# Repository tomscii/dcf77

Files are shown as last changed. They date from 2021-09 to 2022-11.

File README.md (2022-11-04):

## DCF77 clock and temperature/humidity sensor with ATmega328P

(https://tomscii.sig7.se/images/dcf77/final.jpg)

Read the story: https://tomscii.sig7.se/dcf77

### Project organisation

- `doc` - documentation, design notes
- `doc/contrib` - datasheets and specs
- `src` - software (MCU)
- `sim` - simulator (simavr)
- `hw` - hardware design (KiCAD)

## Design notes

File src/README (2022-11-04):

Type 'make' in this directory to compile the firmware.

Type 'make dude' to program the firmware into the device connected to
the AVR programmer.

Keep in mind: the CPU core runs at a clock speed of 250 kHz (much
lower than usual) to save power. This has a number of implications,
e.g., the USART runs at a baudrate of 2400.

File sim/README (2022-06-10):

To get up and running, install simavr (command for debian bullseye):

    sudo apt-get install simavr libsimavr2 libsimavrparts1 libsimavr-dev libelf-dev

The simgui (running in a subprocess, spawned by simulator) requires tcl/tk, while
the serial console uses picocom.

    sudo apt-get install picocom tk

Type `make' in this directory to build the firmware (with simulation
bits) and the simulator itself.

Run the simulation:
    export SIMAVR_UART_XTERM=1
    ./simulator

Open the trace:
    gtkwave trace.vcd

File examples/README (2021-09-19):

Small code examples of programming the AVR with avr-libc,
written with the aim of research and development of certain features.
Contains samples copied from Internet sources.

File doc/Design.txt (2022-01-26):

# DCF77 clock
Planned features:
- DCF77-driven
	- HH:MM:SS, YY.mm.dd, day-of-week
- programmable alarm sound
- stopwatch
- adjustable backlight
- temperature+humidity sensor
- random number generator (6 digits simulating one dice each, with numbers 1-6)
- serial console output (and maybe input) via FTDI header
- powered by 2x AA batteries

DCF77 receiver module
https://www.conrad.com/p/dcf-receiver-module-641138-suitable-for-series-c-control-641138
(we already have one, and it works!)

ATMEGA328P developer board, Arduino Nano-compatible, with soldered pins
https://www.electrokit.com/produkt/utvecklingskort-atmega328p-nano-kompatibelt-monterat/ 79.00 kr

(ATMEGA328P developer board, Arduino Nano-compatible, WITHOUT soldered pins
https://www.electrokit.com/produkt/utvecklingskort-atmega328p-nano-kompatibelt/ 79.00 kr)

(LCD 0.5" 6-digit 7-segment reflective
https://www.electrokit.com/produkt/lcd-0-5-6-siffror-reflective/ 67.50 kr)

(LCD 0.5" 6-digit 7-segment transflective
https://www.electrokit.com/produkt/lcd-0-5-6-siffror-transflective/ 73.75 kr)

LCD 0.5" 6-digit 7-segment transmissive
https://www.electrokit.com/produkt/lcd-0-5-6-siffror-transmissive/ 39.00 kr

Backlight for LCD
https://www.electrokit.com/produkt/bakgrundsbelysning-for-lcd-78-5-x-23mm/ 30.00 kr

Note: it is the transmissive LCD that works best with the backlight.
Having the backlight module behind the LCD, even with no light, makes
the LCD clearly visible (gives it a clear background).

74HC595 DIP-16 8-bit shift register with output latches
https://www.electrokit.com/produkt/74hc595-dip-16-8-bit-shift-register-with-output-latches/
53.10 kr (10 pcs.)
https://www.electrokit.com/produkt/dil-hallare-16-pin/ 2.00 kr (x6)

ATmega328p
https://www.electrokit.com/produkt/atmega328p-pu-dip-28n-8-bit-mcu-flash-32k-picopower/
39.00 kr (x3)
https://www.electrokit.com/produkt/dil-hallare-28-pin-0-3/ 3.50 kr

Piezo (buzzer)
https://www.electrokit.com/produkt/piezoelement-o12x5-5mm/ 15.00 kr

Tryckknapp PCB
https://www.electrokit.com/produkt/tryckknapp-pcb-12x12x8mm/ 9.00 kr (x4)

Temp+humidity sensor
https://www.electrokit.com/produkt/temp-fuktsensor-rht03/ 99.00 kr
connector on mainboard to hold it near the backside
https://www.electrokit.com/produkt/hylslist-2-54mm-1x4p-vinklad/ 9.00 kr

Battery holder
https://www.electrokit.com/produkt/batterihallare-2xaa-sladd/ 9.00 kr
https://www.electrokit.com/produkt/jst-rcy-sats-med-hane-hona/ 8.00 kr
Megj.: PCB-be forrasztott derekszogu 2 polusu tuskesorra megy az aljzat, elemtartora a dugo.

Proto-board
https://www.electrokit.com/produkt/experimentkort-for-pc002/ 30.00 kr
(https://www.electrokit.com/produkt/experimentkort-for-41015692/ 29.0 kr)

Doboz
https://www.electrokit.com/produkt/apparatlada-pc002-med-haltagning-gra/ (85x50x21) 15.00 kr
(https://www.electrokit.com/produkt/apparatlada-gra-100x60x25mm/ (100x60x25) 25.00 kr)

## IO port usage

- port X:
	- bit 0-5: 6-bit parallel output into 6 shifted lines (6x8 bits) driving LCD segment pins
	  (Further 6 bits can be obtained from directly using the LCD DATA output of our MCU.)
  - bit 6: CLK (all 74HC595 chips' SH_CP and ST_CP pins in one)
	- bit 7: OE (Output Enable) of all 6 shift registers
	  Note: we might not need this (wire to enable instead); we can put the LCD COM pin in tri-state.
- port Y:
	- bit 0: output, drives LCD module COM (common) pin
  - bit 1: drive background lighting LEDs (TODO provision 3 pins for RGB)
  - bit 2: output, drives buzzer
  - bit 3: input/output, connected to DHT22 sensor's DATA signal
  - bit 4: input from DCF77 receiver module
  - bit 5-7: input from 3 pushbuttons
+ UART RX, TX

1 - PC6 - RESET/ (AVRPROG)
2 - PD0 - RXD - to FTDI pin 4 (orange-TXD)
3 - PD1 - TXD - to FTDI pin 5 (yellow-RXD)
4 - PD2 - DHT22 DATA I/O
5 - PD3 - OC2B - PWM - LED R
6 - PD4 - DHT22 POWER
7 - VCC (POWER)
8 - GND (POWER)
9 - XTAL1 (OSC)
10 - XTAL2 (OSC)
11 - PD5 - OC0B - PWM - LED G
12 - PD6 - OC0A - PWM - PiezoBuzzer
13 - PD7 - DCF77 POWER
14 - PB0 - ICP1 - DCF77 S-

15 - PB1 - BUTTON2
16 - PB2 - BUTTON1
17 - PB3 - OC2A - PWM - LED B + MOSI (AVRPROG)
18 - PB4 - BUTTON0 + MISO (AVRPROG)
19 - PB5 - SCK (AVRPROG)
20 - AVCC (POWER)
21 - AREF (POWER)
22 - GND (POWER)
23 - PC0 - LCD DATA0
24 - PC1 - LCD DATA1
25 - PC2 - LCD DATA2
26 - PC3 - LCD CLK
27 - PC4 - LCD COM
28 - PC5 - LCD OE/

LED resistors: R 150, G 680, B 470 ohm.

## Component placement
Fit the processor on the same board as the display driver shift registers.
We only need sockets for the LCD module (2x25-pin socket rails near the long edges of the board) so we can remove the LCD and access the microchips underneath.

## Literature

ATmega328p datasheet: https://www.electrokit.com/uploads/productfile/40360/doc8161.pdf
Getting started guide: https://github.com/amirbawab/AVR-cheat-sheet

## Development

$ apt-get install gcc-avr binutils-avr avr-libc gdb-avr avrdude

$ avrdude -c usbtiny -p atmega328p
avrdude: AVR device initialized and ready to accept instructions
Reading | ################################################## | 100% 0.06s
avrdude: Device signature = 0x1e950f (probably m328p)
avrdude: safemode: Fuses OK (E:FF, H:D9, L:62)
avrdude done.  Thank you.

$ cat blink.c
#ifndef F_CPU
#define F_CPU 1000000UL
#endif

#include <avr/io.h>
#include <util/delay.h>

int main(void) {
        DDRC |= (1 << PC5);
        while (1) {

                // Toggle LED at port PC5
                PORTC ^= (1 << PC5);

                // Delay for 500ms
                _delay_ms(500);
        }
        return 0;
}

$ avr-gcc -Wall -g -Os -mmcu=atmega328p -o blink.bin blink.c
$ avr-objcopy -j .text -j .data -O ihex blink.bin blink.hex
$ avrdude -c usbtiny -p atmega328p -U flash:w:blink.hex

Device signature: 1E 95 0F = 0001 1110 1001 0101 0000 1111

To change the clock to using 40kHz crystal, program 0xE5 as the lower fuse bit value by adding -Ulfuse:w:0xe5:m to the avrdude command line. (Also change F_CPU above to 40000UL.)

Attention: from this point, use a low bitclock (-B 10kHz) or else the device won't answer!
Complete command line:
$ avrdude -c usbtiny -p atmega328p -B 10kHz -U flash:w:blink.hex -Ulfuse:w:0xe5:m

# Aux Supplies
Forraszfelszívó rézsodrony, hogy ki tudjam forrasztani a dcf77 modulra rakott csatit. A helyére tüskesor kerül, ami a főkártyán levő aljzatba csatlakozik.
https://www.electrokit.com/produkt/lodflata-2-7mm/ 35.00 kr
Fokartya aljzat (hatoldalon, hogy a dcf77 panel vele parhuzamos legyen):
https://www.electrokit.com/produkt/hylslist-2-54mm-1x8p-vinklad/ 15.00 kr

Forrasztoallomas
https://www.electrokit.com/produkt/lodstation-variabel-effekt-vtss4-ap-2/
199.00 kr

Sparkfun Pocket AVR programmer
https://www.electrokit.com/produkt/avr-pocket-programmer/
199 kr
Keszulekre programozo csatlakozo:
https://www.electrokit.com/produkt/idc-hane-pcb-6-pol-2-54mm/ 6.00 kr
https://www.electrokit.com/produkt/idc-hane-pcb-10-pol-2-54mm/ 5.04 kr
(https://www.electrokit.com/produkt/idc-hane-pcb-10-pol-vinklad-2-54mm/ 6.50 kr)
Megj.: valoszinuleg nem fer el egyik sem, sima 2x3-polusu tuskesor lesz beforrasztva.

- LEDs
  https://www.electrokit.com/produkt/led-3mm-rod-diffus-1300mcd/ 45.00 kr (10 pcs)
	https://www.electrokit.com/produkt/led-3mm-orange-diffus-600mcd/ 45.00 kr (10 pcs)
	https://www.electrokit.com/produkt/led-3mm-gron-diffus-70mcd/ 45.00 kr (10 pcs)
	https://www.electrokit.com/produkt/led-5mm-rod-diffus-1500mcd/ 5.00 kr
	https://www.electrokit.com/produkt/led-5mm-orange-diffus-700mcd/ 5.00 kr
	https://www.electrokit.com/produkt/led-5mm-gron-diffus-80mcd/ 5.00 kr
	https://www.electrokit.com/produkt/led-5mm-rgb-diffus-cc/ 6.00 kr

- Clock quartz, various freqs
  https://www.electrokit.com/produkt/kristall-16-0000-mhz-hc49-s/ 12.00 kr
  https://www.electrokit.com/produkt/kristall-8-000-mhz-hc-49-u-30-pf/ 12.00 kr
	https://www.electrokit.com/produkt/kristall-8-000mhz-o3x8mm-30ppm/ 5.00 kr
	https://www.electrokit.com/produkt/kristall-2mhz-hc-49-u/ 19.00 kr
	https://www.electrokit.com/produkt/kristall-100khz-o2x6mm-15pf-100ppm/ 25.00 kr
	https://www.electrokit.com/produkt/kristall-40-000khz-o3x8mm/ 15.00 kr
	https://www.electrokit.com/produkt/kristall-38-000khz-o3x8mm/ 12.00 kr

- Kondensatorsats keramisk 108st
  https://www.electrokit.com/produkt/kondensatorsats-keramisk-108-st/
	49.00 kr

- Stiftlist & hylslist
  https://www.electrokit.com/produkt-kategori/kontaktdon-2/stiftlist-hylslist/2-54mm/
	- kell 2 db 1x25 aljzat, az LCD modulnak
	  https://www.electrokit.com/produkt/hylslist-2-54mm-1x40p-svarvad-brytbar/ 15.00 kr x2

    https://www.electrokit.com/produkt/stiftlist-2-54mm-1x40p-brytbar/ 9.00 kr x4
    https://www.electrokit.com/produkt/stiftlist-2-54mm-1x40p-vinklad-brytbar/ 11.00 kr x2
		https://www.electrokit.com/produkt/stiftlist-2-54mm-2x40p-brytbar-guld/ 18.00 kr
		https://www.electrokit.com/produkt/stiftlist-2-54mm-2x40p-vinklad-brytbar/ 19.00 kr
		https://www.electrokit.com/produkt/hylslist-2-54mm-1x40p/ 19.00 kr x2
		https://www.electrokit.com/produkt/hylslist-2-54mm-2x20p/ 15.75 kr x2

- Breadboard
  https://www.electrokit.com/produkt/kopplingsdack-840-anslutningar/ 69.00 kr
	https://www.electrokit.com/produkt/kopplingstrad-byglar-for-kopplingsdack/ 59.00 kr
- https://www.electrokit.com/produkt/labbsladd-20-pin-15cm-hona-hane/ 29.00 kr
- https://www.electrokit.com/produkt/labbsladd-20-pin-15cm-hona-hona/ 29.00 kr

- Kabelskalare
  https://www.electrokit.com/produkt/kabelskalare-sjalvjusterande-velleman/ 69.00 kr

- Kopplingstråd
  https://www.electrokit.com/produkt/kopplingstrad-entradig-sats-60m/ 149.00 kr
	https://www.electrokit.com/produkt/kopplingstrad-flertradig-sats-60m/ 149.00 kr

- valami forrasztos proto-board (PCB helyett)
	https://www.electrokit.com/produkt/experimentkort-for-41015692/
	https://www.electrokit.com/produkt/experimentkort-1-hal-80x120mm-genomplaterade-hal/
	https://www.electrokit.com/produkt/experimentkort-1-hal-100x80-fr4/
	https://www.electrokit.com/produkt/experimentkort-1-hal-100x160-fr4/
	https://www.electrokit.com/produkt/experimentkort-breadboard-400-hal/

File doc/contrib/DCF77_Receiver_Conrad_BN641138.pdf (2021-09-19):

# Connection line DCF – Receiver

BN 641138

## Frankfurt

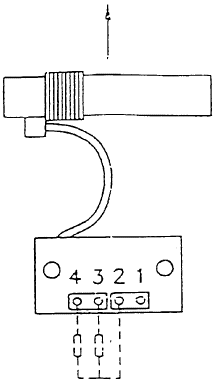
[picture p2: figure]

pull up resistance
if necessary

R > UB : 1 mA

1: Earth
2: + operating voltage 1.2 … 1.5 V-3: DCF output
4: DCF output inverted

Outputs 3 and 4 of open collectors npn max. 30 V 1 mA

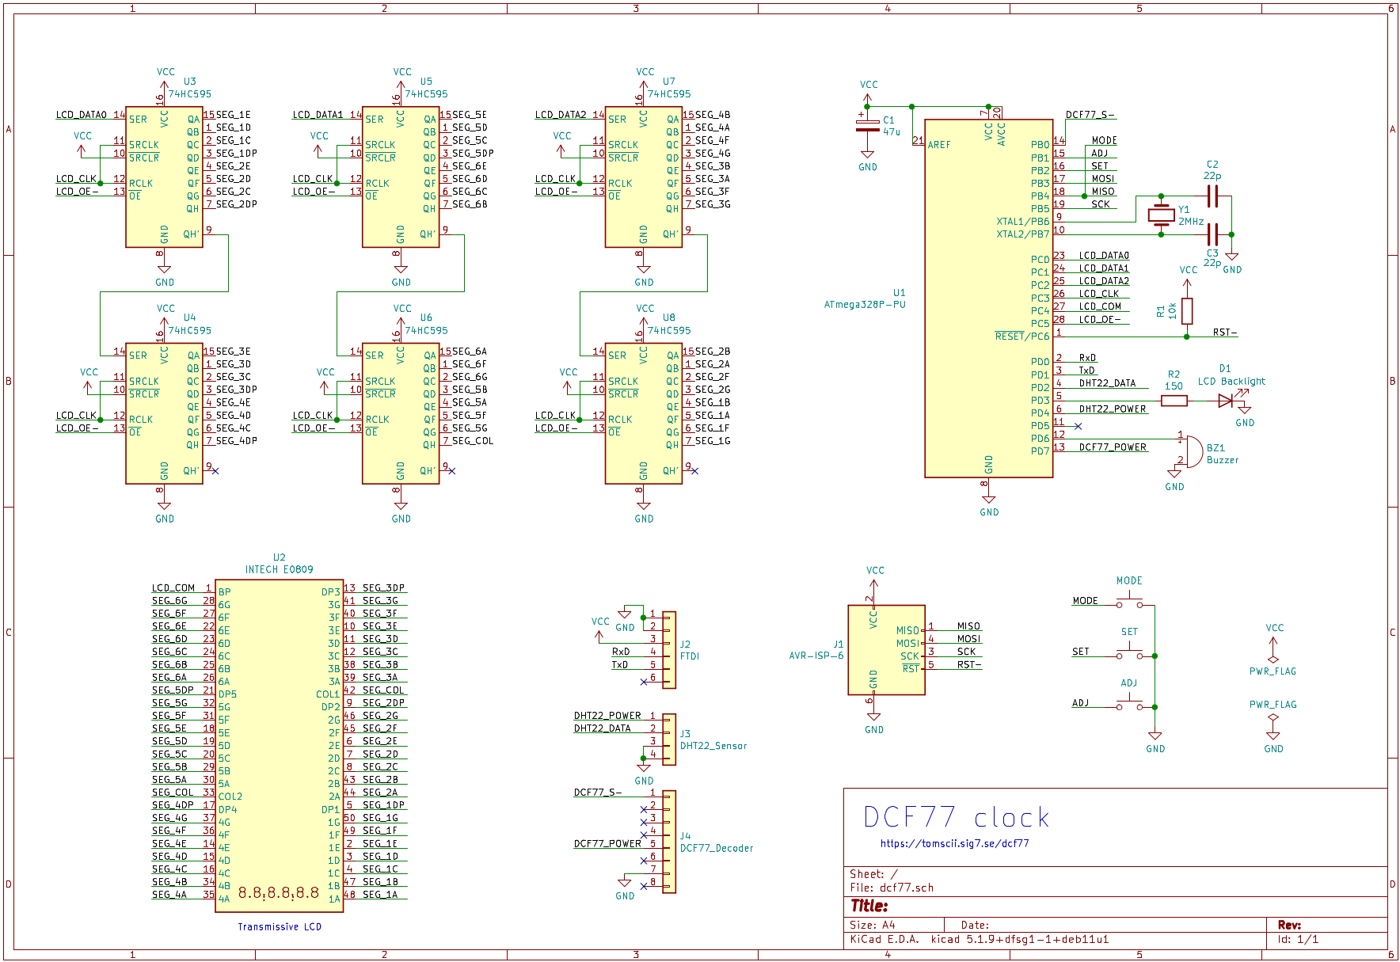
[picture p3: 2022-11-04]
doc/schematic.png

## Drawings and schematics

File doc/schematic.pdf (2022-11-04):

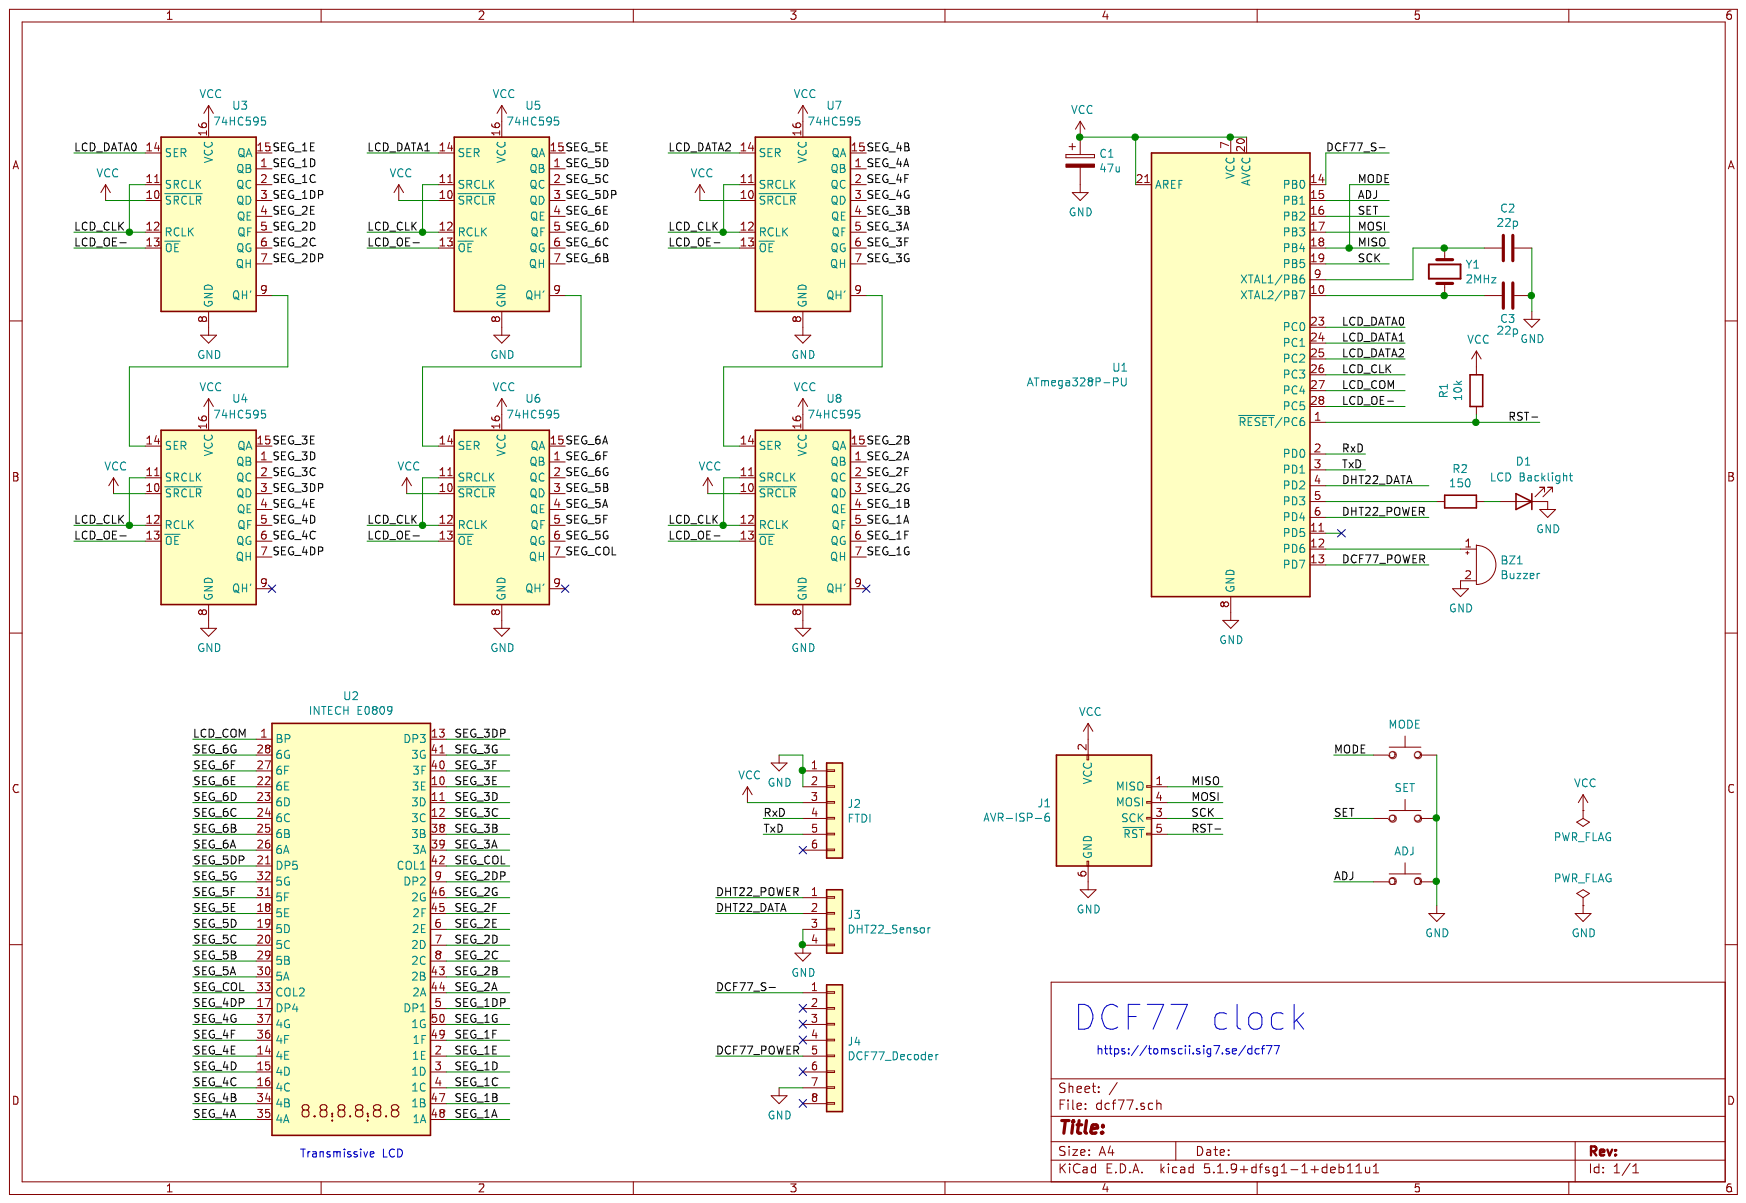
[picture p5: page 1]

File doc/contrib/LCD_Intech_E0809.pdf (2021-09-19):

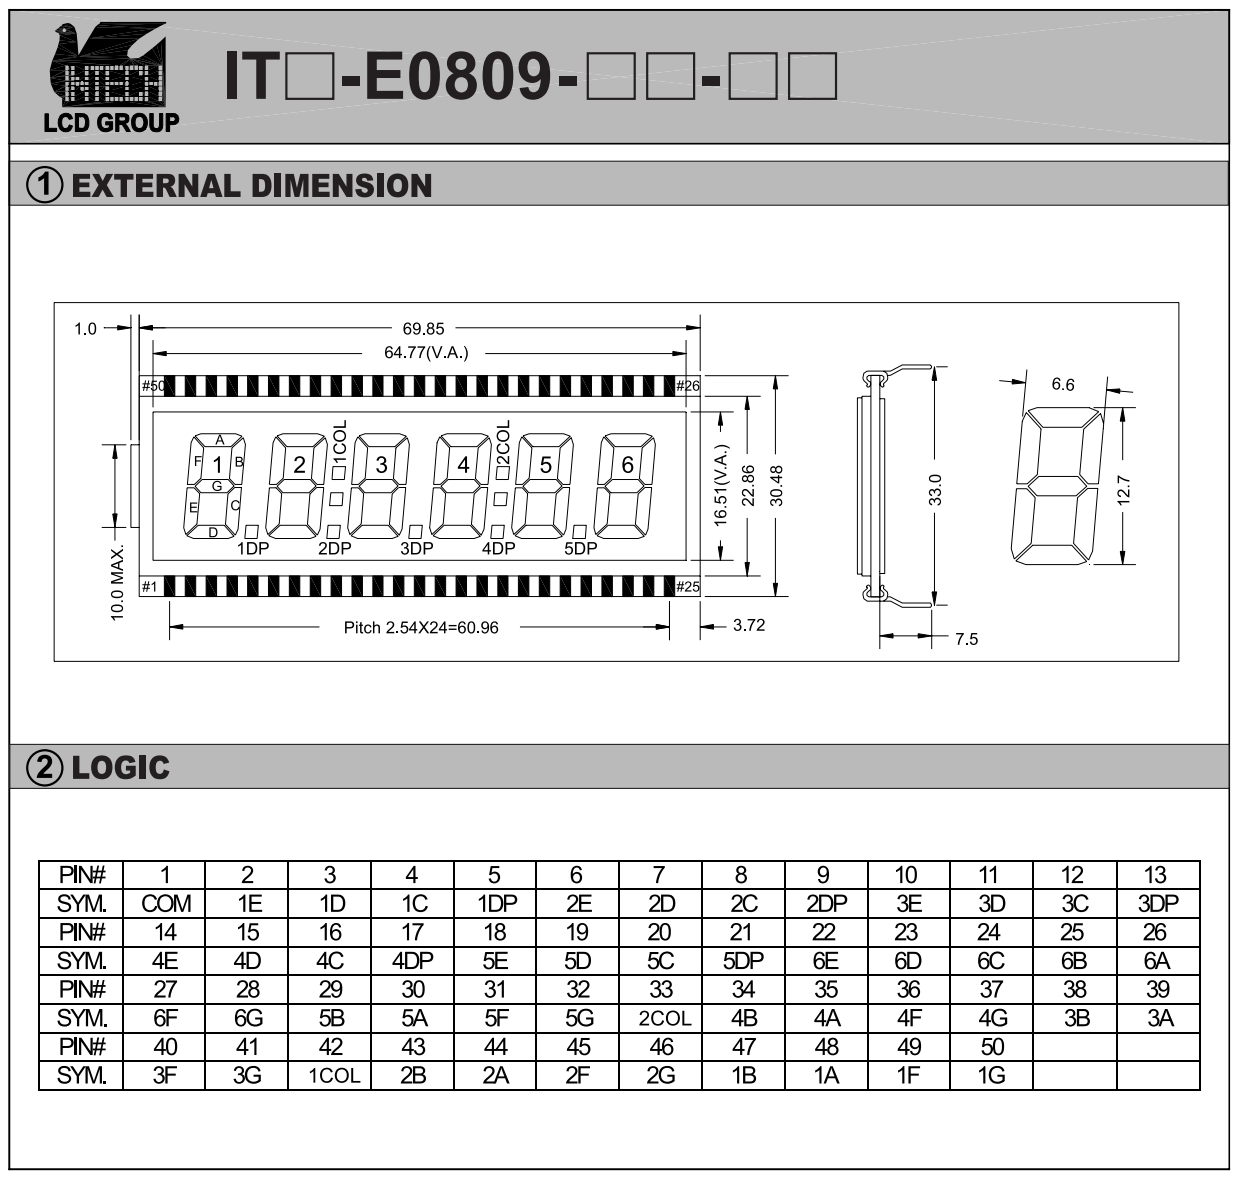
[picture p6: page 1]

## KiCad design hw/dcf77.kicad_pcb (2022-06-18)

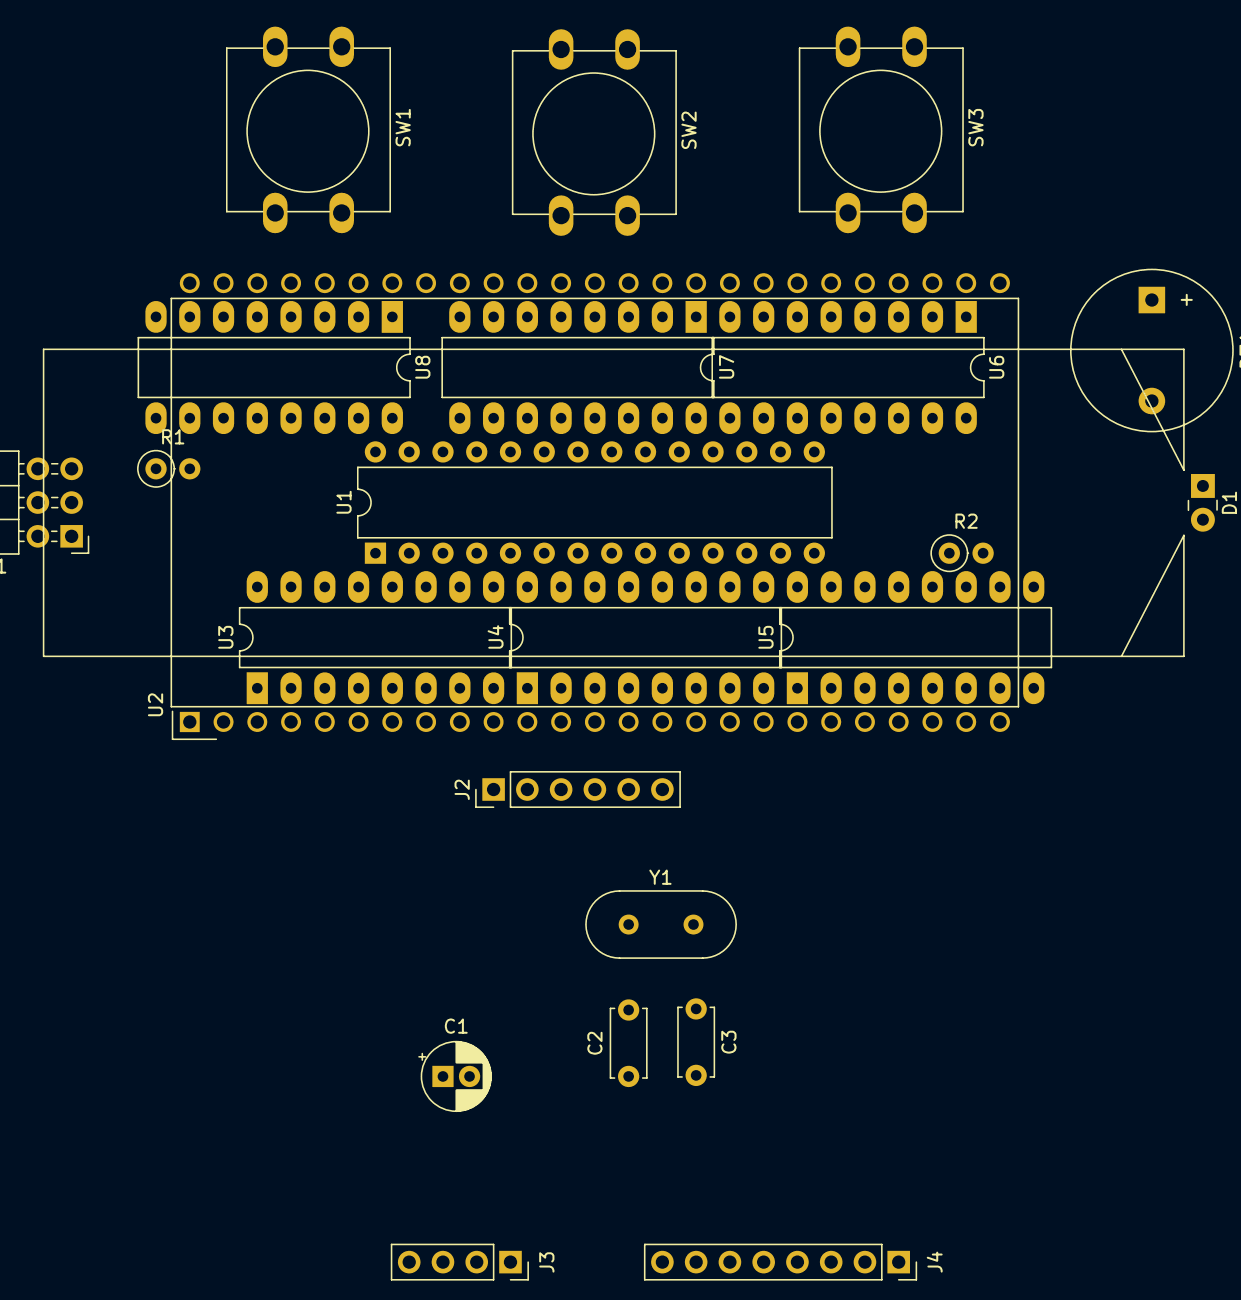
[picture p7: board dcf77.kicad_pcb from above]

Board: 2 copper layers, 23 parts (0 on the bottom side), 76 nets, no tracks yet.

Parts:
BZ1: Buzzer; Buzzer_12x9.5RM7.6
C1: 47u; CP_Radial_D5.0mm_P2.00mm
C2, C3: 22p; C_Disc_D5.0mm_W2.5mm_P5.00mm
D1: LCD Backlight; LED_backlight_COM0621
J1: AVR-ISP-6; PinHeader_2x03_P2.54mm_Horizontal
J2: FTDI; PinHeader_1x06_P2.54mm_Vertical
J3: DHT22_Sensor; PinSocket_1x04_P2.54mm_Vertical
J4: DCF77_Decoder; PinSocket_1x08_P2.54mm_Vertical
R1: 10k; R_Axial_DIN0207_L6.3mm_D2.5mm_P2.54mm_Vertical
R2: 150; R_Axial_DIN0207_L6.3mm_D2.5mm_P2.54mm_Vertical
SW1: MODE; SW_PUSH-12mm
SW2: SET; SW_PUSH-12mm
SW3: ADJ; SW_PUSH-12mm
U1: ATmega328P-PU; DIP-28_W7.62mm
U2: DE122-XX-XX
U3, U4, U5, U6, U7, U8: 74HC595; DIP-16_W7.62mm_LongPads
Y1: 2MHz; Crystal_HC49-U_Vertical

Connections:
/ADJ: SW3.1, U1.15
/DCF77_POWER: J4.5, U1.13
/DCF77_S-: J4.1, U1.14
/DHT22_DATA: J3.2, U1.4
/DHT22_POWER: J3.1, U1.6
/LCD_CLK: U1.26, U3.11, U3.12, U4.11, U4.12, U5.11, U5.12, U6.11, U6.12, U7.11, U7.12, U8.11, U8.12
/LCD_COM: U1.27, U2.1
/LCD_DATA0: U1.23, U3.14
/LCD_DATA1: U1.24, U5.14
/LCD_DATA2: U1.25, U7.14
/LCD_OE-: U1.28, U3.13, U4.13, U5.13, U6.13, U7.13, U8.13
/MISO: J1.1, SW1.1, U1.18
/MOSI: J1.4, U1.17
/RST-: J1.5, R1.2, U1.1
/RxD: J2.4, U1.2
/SCK: J1.3, U1.19
/SEG_1A: U2.48, U8.5
/SEG_1B: U2.47, U8.4
/SEG_1C: U2.4, U3.2
/SEG_1D: U2.3, U3.1
/SEG_1DP: U2.5, U3.3
/SEG_1E: U2.2, U3.15
/SEG_1F: U2.49, U8.6
/SEG_1G: U2.50, U8.7
/SEG_2A: U2.44, U8.1
/SEG_2B: U2.43, U8.15
/SEG_2C: U2.8, U3.6
/SEG_2D: U2.7, U3.5
/SEG_2DP: U2.9, U3.7
/SEG_2E: U2.6, U3.4
/SEG_2F: U2.45, U8.2
/SEG_2G: U2.46, U8.3
/SEG_3A: U2.39, U7.5
/SEG_3B: U2.38, U7.4
/SEG_3C: U2.12, U4.2
/SEG_3D: U2.11, U4.1
/SEG_3DP: U2.13, U4.3
/SEG_3E: U2.10, U4.15
/SEG_3F: U2.40, U7.6
/SEG_3G: U2.41, U7.7
/SEG_4A: U2.35, U7.1
/SEG_4B: U2.34, U7.15
/SEG_4C: U2.16, U4.6
/SEG_4D: U2.15, U4.5
/SEG_4DP: U2.17, U4.7
/SEG_4E: U2.14, U4.4
/SEG_4F: U2.36, U7.2
/SEG_4G: U2.37, U7.3
/SEG_5A: U2.30, U6.4
/SEG_5B: U2.29, U6.3
/SEG_5C: U2.20, U5.2
/SEG_5D: U2.19, U5.1
/SEG_5DP: U2.21, U5.3
/SEG_5E: U2.18, U5.15
/SEG_5F: U2.31, U6.5
/SEG_5G: U2.32, U6.6
/SEG_6A: U2.26, U6.15
/SEG_6B: U2.25, U5.7
/SEG_6C: U2.24, U5.6
/SEG_6D: U2.23, U5.5
/SEG_6E: U2.22, U5.4
/SEG_6F: U2.27, U6.1
/SEG_6G: U2.28, U6.2
/SEG_COL: U2.33, U2.42, U6.7
/SET: SW2.1, U1.16
/TxD: J2.5, U1.3
GND: BZ1.2, C1.2, C2.1, C3.2, D1.1, J1.6, J2.1, J2.2, J3.3, J3.4, J4.7, SW1.2, SW2.2, SW3.2, U1.8, U1.22, U3.8, U4.8, U5.8, U6.8, U7.8, U8.8
unnamed: BZ1.1, U1.12
unnamed: C2.2, U1.9, Y1.1
unnamed: C3.1, U1.10, Y1.2
unnamed: D1.2, R2.1
unnamed: R2.2, U1.5
unnamed: U3.9, U4.14
unnamed: U5.9, U6.14
unnamed: U7.9, U8.14
VCC: C1.1, J1.2, J2.3, R1.1, U1.7, U1.20, U1.21, U3.10, U3.16, U4.10, U4.16, U5.10, U5.16, U6.10, U6.16, U7.10, U7.16, U8.10, U8.16

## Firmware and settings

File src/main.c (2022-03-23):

#include "backlight.h"
#include "clock.h"
#include "common.h"
#include "dcf77.h"
#include "dht22.h"
#include "lcd.h"
#include "pbtn.h"
#include "pwm.h"
#include "usart.h"
#include "utils.h"

#include <stdint.h>

#include <avr/interrupt.h>
#include <avr/io.h>
#include <avr/power.h>
#include <avr/sleep.h>

enum screen_t
{
   S_TIME_OF_DAY = 0, S_DATE, S_DAY_OF_WEEK, S_TEMPERATURE, S_HUMIDITY,
   S_COUNT
};
enum screen_t screen = S_TIME_OF_DAY;
char display_full_update = 1;

#define INPUT_BUFSIZE 16
char input [INPUT_BUFSIZE];
uint8_t input_count;

char echo = 0;

void
ioinit (void)
{
   // set up clock prescaler for MCU clock
   CLKPR = _BV (CLKPCE);
   //CLKPR = _BV (CLKPS0);                  //  /2 -> 1 MHz
   CLKPR = _BV (CLKPS1) | _BV (CLKPS0);   //  /8 -> 250 kHz
   //CLKPR = _BV (CLKPS2);                  // /16 -> 125 kHz

   // set all IO pins as input, pull-up active
   PORTB = 0xff;
   DDRB = 0;
   PORTC = 0xff;
   DDRC = 0;
   PORTD = 0xff;
   DDRD = 0;

   // disable unused peripherals to save power
   ADCSRA &= ~_BV (ADEN);       // disable ADC
   ACSR |= _BV (ACD);           // disable Analog Comparator
   SPCR &= ~_BV (SPE);          // disable SPI
   TWCR &= ~_BV (TWEN);         // disable TWI

   power_all_disable ();

   usart_setup (); // this is first to allow printouts in later setup functions
   clock_setup ();
   dcf77_setup ();
   dht22_setup ();
   lcd_setup ();
   pbtn_setup ();
   pwm_setup ();

   sei ();
}

void
process_input ()
{
   switch (input [input_count - 1])
   {
   case '\b': // Backspace key
      input_count = 0;
      break;
   case 's': // set time
      if (input_count == 5)  // HHMMs
      {
         uint8_t hours = 10 * (input [0] - '0') + input [1] - '0';
         uint8_t minutes = 10 * (input [2] - '0') + input [3] - '0';
         clock_set_hms (hours, minutes, 0);
      }
      else if (input_count == 7)  // HHMMSSs
      {
         uint8_t hours = 10 * (input [0] - '0') + input [1] - '0';
         uint8_t minutes = 10 * (input [2] - '0') + input [3] - '0';
         uint8_t seconds = 10 * (input [4] - '0') + input [5] - '0';
         clock_set_hms (hours, minutes, seconds);
      }
      input_count = 0;
      break;
   case 'a': // clock adjust (test)
      clock_adjust (1000);
      input_count = 0;
      break;
   case 'A': // clock adjust (test)
      clock_adjust (-200);
      input_count = 0;
      break;
   case 'Z': // zero out clock adjustment
      clock_adjust_reset ();
      input_count = 0;
      break;
   case 'e': // echo on
      echo = 1;
      input_count = 0;
      break;
   case 'E': // echo off
      echo = 0;
      input_count = 0;
      break;
   case 't': // nudge time forward
      clock_plus_jiffy ();
      input_count = 0;
      break;
   case 'T': // nudge time backward
      clock_minus_jiffy ();
      input_count = 0;
      break;
   case 'm': // measure humidity + temperature sensor
      dht22_schedule ();
      input_count = 0;
      break;
   case 'w': // DHT22 power on
      dht22_power_set (1);
      input_count = 0;
      break;
   case 'W': // DHT22 power off
      dht22_power_set (0);
      input_count = 0;
      break;
   case 'v': // DCF77 power on
      dcf77_power_set (1);
      input_count = 0;
      break;
   case 'V': // DCF77 power off
      dcf77_power_set (0);
      input_count = 0;
      break;
   case 'r': // nudge red channel up
      pwm_nudge_led (IDX_LED_R, 8);
      input_count = 0;
      break;
   case 'R': // nudge red channel down
      pwm_nudge_led (IDX_LED_R, -8);
      input_count = 0;
      break;
   case 'g': // nudge green channel up
      pwm_nudge_led (IDX_LED_G, 8);
      input_count = 0;
      break;
   case 'G': // nudge green channel down
      pwm_nudge_led (IDX_LED_G, -8);
      input_count = 0;
      break;
   case 'b': // nudge blue channel up
      pwm_nudge_led (IDX_LED_B, 8);
      input_count = 0;
      break;
   case 'B': // nudge blue channel down
      pwm_nudge_led (IDX_LED_B, -8);
      input_count = 0;
      break;
   case 'p': // piezo on
      pwm_piezo_set (1);
      input_count = 0;
      break;
   case 'P': // piezo off
      pwm_piezo_set (0);
      input_count = 0;
      break;
   default:
      break;
   }
}

void
display_tod ()
{
   if (clock_flags.ovf_minutes || display_full_update)
   {
      clock_flags.ovf_minutes = 0;

      if (clock.hours < 10)
         lcd_set_digit (1, ' ');
      else
         lcd_set_digit (1, '0' + (clock.hours / 10));
      lcd_set_digit (2, '0' + (clock.hours % 10));
   }
   if (clock_flags.ovf_seconds || display_full_update)
   {
      clock_flags.ovf_seconds = 0;

      lcd_set_digit (3, '0' + (clock.minutes / 10));
      lcd_set_digit (4, '0' + (clock.minutes % 10));
   }

   lcd_set_digit (5, '0' + (clock.seconds / 10));
   lcd_set_digit (6, '0' + (clock.seconds % 10));

   lcd_set_dot (2, clock.dst);

   if (display_full_update)
   {
      lcd_set_dot (1, 0);
      lcd_set_dot (3, 0);
      lcd_set_dot (4, 0);
      lcd_set_colons (1);
   }
}

void
display_date ()
{
   if (clock_flags.ovf_months || display_full_update)
   {
      clock_flags.ovf_months = 0;

      lcd_set_digit (1, '0' + (clock.year / 10));
      lcd_set_digit (2, '0' + (clock.year % 10));
   }
   if (clock_flags.ovf_days || display_full_update)
   {
      clock_flags.ovf_days = 0;

      lcd_set_digit (3, '0' + (clock.month / 10));
      lcd_set_digit (4, '0' + (clock.month % 10));
   }
   if (clock_flags.ovf_hours || display_full_update)
   {
      clock_flags.ovf_hours = 0;

      lcd_set_digit (5, '0' + (clock.day / 10));
      lcd_set_digit (6, '0' + (clock.day % 10));
   }
   if (display_full_update)
   {
      lcd_set_dot (1, 0);
      lcd_set_dot (2, 1);
      lcd_set_dot (3, 0);
      lcd_set_dot (4, 1);
      lcd_set_colons (0);
   }
}

void
display_dow ()
{
   if (clock_flags.ovf_hours || display_full_update)
   {
      clock_flags.ovf_hours = 0;

      lcd_set_digit (4, '0' + (clock.dow));
   }
   if (display_full_update)
   {
      lcd_set_digit (1, ' ');
      lcd_set_digit (2, ' ');
      lcd_set_digit (3, 'd');
      lcd_set_digit (5, ' ');
      lcd_set_digit (6, ' ');
      lcd_set_dot (1, 0);
      lcd_set_dot (2, 0);
      lcd_set_dot (3, 1);
      lcd_set_dot (4, 0);
      lcd_set_colons (0);
   }
}

void
display_temp ()
{
   if (dht22_status.updated || display_full_update)
   {
      dht22_status.updated = 0;

      int16_t temp = dht22_status.temp_last;
      if (temp < -99)
      {
         lcd_set_digit (1, '-');
         temp = -temp;
         lcd_set_digit (2, '0' + temp / 100);
      }
      else if (temp < 0)
      {
         lcd_set_digit (1, ' ');
         lcd_set_digit (2, '-');
         temp = -temp;
      }
      else if (temp < 100)
      {
         lcd_set_digit (1, ' ');
         lcd_set_digit (2, ' ');
      }
      else
      {
         lcd_set_digit (1, ' ');
         lcd_set_digit (2, '0' + temp / 100);
      }
      lcd_set_digit (3, '0' + (temp % 100) / 10);
      lcd_set_digit (4, '0' + (temp % 10));
   }
   if (display_full_update)
   {
      lcd_set_digit (5, '*'); // degree sign
      lcd_set_digit (6, 'C');
      lcd_set_dot (1, 0);
      lcd_set_dot (2, 0);
      lcd_set_dot (3, 1);
      lcd_set_dot (4, 0);
      lcd_set_colons (0);
   }
}

void
display_rh ()
{
   if (dht22_status.updated || display_full_update)
   {
      dht22_status.updated = 0;

      int16_t rh = dht22_status.rh_last;
      if (rh >= 1000)
      {
         lcd_set_digit (1, '1');
         lcd_set_digit (2, '0' + (rh - 1000) / 100);
      }
      else if (rh >= 100)
      {
         lcd_set_digit (1, ' ');
         lcd_set_digit (2, '0' + rh / 100);
      }
      else
      {
         lcd_set_digit (1, ' ');
         lcd_set_digit (2, ' ');
      }

      lcd_set_digit (3, '0' + (rh % 100) / 10);
      lcd_set_digit (4, '0' + (rh % 10));
   }
   if (display_full_update)
   {
      lcd_set_digit (5, 'r');
      lcd_set_digit (6, 'h');
      lcd_set_dot (1, 0);
      lcd_set_dot (2, 0);
      lcd_set_dot (3, 1);
      lcd_set_dot (4, 0);
      lcd_set_colons (0);
   }
}

void
display_blank ()
{
   if (display_full_update)
   {
      lcd_set_digit (1, ' ');
      lcd_set_digit (2, ' ');
      lcd_set_digit (3, ' ');
      lcd_set_digit (4, ' ');
      lcd_set_digit (5, ' ');
      lcd_set_digit (6, ' ');
      lcd_set_dot (1, 0);
      lcd_set_dot (2, 0);
      lcd_set_dot (3, 0);
      lcd_set_dot (4, 0);
      lcd_set_colons (0);
   }
}

void
display_update ()
{
   switch (screen)
   {
   case S_TIME_OF_DAY: display_tod (); break;
   case S_DATE:        display_date (); break;
   case S_DAY_OF_WEEK: display_dow (); break;
   case S_TEMPERATURE: display_temp (); break;
   case S_HUMIDITY:    display_rh (); break;
   default: display_blank (); break;
   }

   display_full_update = 0;

}

void
next_screen ()
{
   if (++screen == S_COUNT)
      screen = 0;

   dht22_measure_interval (screen == S_TEMPERATURE || screen == S_HUMIDITY);

   display_full_update = 1;
}

void
process_event (uint8_t evt)
{
   if (evt & F_EVT_TOUCH)
   {
      if ((evt & F_BTN_MASK) == F_BTN_MODE)
      {
         if (backlight_set (1))
         {
            // backlight was already on
            next_screen ();
         }
      }
   }
   else if (evt & F_EVT_HOLD)
   {
      if ((evt & F_BTN_MASK) == F_BTN_MODE)
      {
         backlight_set (1); // already on, but restart counter
         next_screen ();
      }
      else if ((evt & F_BTN_MASK) == (F_BTN_MODE | F_BTN_ADJ))
      {
         dcf77_schedule_sync ();
         backlight_set (0); // cut PWM interference to DCF receiver
      }
   }
   else if (evt & F_EVT_RELEASE)
   {
      if ((evt & F_BTN_MASK) == F_BTN_MODE)
      {
         backlight_set (1); // already on, but restart counter
      }
   }

 #if SIMAVR
   put_str ("evt=");
   put_byte_hex (evt);
   put_str ("\r\n");
 #endif
}

void
main_loop ()
{
   if (clock_flags.tick)
   {
      dcf77_on_tick ();
      pbtn_on_tick ();

      if (clock_flags.ovf_jiffies)
      {
         dcf77_on_second ();

         if (echo)
         {
            put_str (d2 [(uint8_t)clock.hours]);
            put_str (":");
            put_str (d2 [(uint8_t)clock.minutes]);
            put_str (":");
            put_str (d2 [(uint8_t)clock.seconds]);
            put_str ("\r\n");
         }
      }
      display_update ();
      lcd_send_frame ();

      dht22_on_tick ();
      if (clock_flags.ovf_jiffies)
      {
         dht22_on_second ();
      }

      backlight_on_tick ();
      clock_flags.ovf_jiffies = 0;
   }
   clock_flags.tick = 0;

   if (usart_flags.rx)
   {
      usart_flags.rx = 0;

      int c;
      while ((c = getchar ()) != EOF)
      {
         putchar (c); // echo

         input [input_count] = c;
         if (input_count < INPUT_BUFSIZE - 1)
            ++input_count;

         process_input ();
      }
      clearerr (stdin);
   }

   if (!pbtn_flags.ack_event && pbtn_flags.pending_event)
   {
      process_event (pbtn_flags.pending_event);
      pbtn_flags.ack_event = 1;
   }
}

int
main ()
{
   ioinit ();

   put_str ("DCF77 booted\r\n");

   for (;;)
   {
      main_loop ();
      sleep_mode ();
   }

   return 0;
}

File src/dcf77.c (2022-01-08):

#include "common.h"
#include "clock.h"
#include "dcf77.h"
#include "lcd.h"
#include "utils.h"

#include <avr/interrupt.h>
#include <avr/io.h>

#define DCF77_POWER_PORT PORTD
#define DCF77_POWER_DDR  DDRD
#define DCF77_POWER      PD7

#define DCF77_DATA_PORT  PORTB
#define DCF77_DATA_DDR   DDRB
#define DCF77_DATA_PIN   PINB
#define DCF77_DATA       PB0

enum dcf77_state_t
{
   POWEROFF, WARMUP, PHASE_ACQ, FRAME_ACQ, SYNCED
};
static enum dcf77_state_t state = POWEROFF;
static int state_seconds = 0; // seconds since state transition

uint8_t phase_acc [F_TICK]; // cumulative no. of active level observations

// The '1' bit is 10 samples long. We start sampling slightly early
// (by about 1-2 jiffies) due to the way the phase detector syncs,
// and leave a similar amount of slack at the end.
#define N_BIT_SAMPLES 15
uint8_t bit_samples [N_BIT_SAMPLES];

uint8_t recv_bit_cnt = 0;
char recv_bits [60];
// special values stored in recv_bits, all < 0:
#define RECV_BIT_MINUTE_MARK    -1
#define RECV_BIT_INVALID        -2

// the time decoded from DCF77, to be loaded into/compared with local clock
struct clock_t dcf77_clock;

uint8_t has_been_synced = 0;
int32_t seconds_since_last_sync; // N.B.: signed for the sake of computation
uint8_t acc_drift_phase = 0;

enum sync_policy_t
{
   SYNC_ASAP, SYNC_HOURLY, SYNC_3HOURLY, SYNC_DAILY
};
enum sync_policy_t sync_policy = SYNC_ASAP;

void dcf77_setup ()
{
   DCF77_POWER_DDR |= _BV (DCF77_POWER);

   dcf77_power_set (1);
   state = WARMUP;
   state_seconds = 0;
}

void dcf77_power_set (char on)
{
   if (on)
   {
      DCF77_POWER_PORT |= _BV (DCF77_POWER);
      // switch DATA pin to input with pull-up:
      DCF77_DATA_DDR &= ~_BV (DCF77_DATA);
      DCF77_DATA_PORT |= _BV (DCF77_DATA);
   }
   else
   {
      DCF77_POWER_PORT &= ~_BV (DCF77_POWER);
      // drive DATA low to avoid bleeding current through pull-up:
      DCF77_DATA_DDR |= _BV (DCF77_DATA);
      DCF77_DATA_PORT &= ~_BV (DCF77_DATA);
   }

   lcd_set_dot (5, on);
}

void dcf77_schedule_sync ()
{
   if (state == POWEROFF)
      sync_policy = SYNC_ASAP;
}

void bcd_decode (char* data, char count, char* parity, char* result)
{
   const char mul [] = {1, 2, 4, 8, 10, 20, 40, 80};

   int8_t k;
   *result = 0;
   for (k = 0; k < count; ++k)
   {
      *parity += data [k];
      *result += mul [k] * data [k];
   }
}

void dcf77_on_tick ()
{
   if (state == POWEROFF)
      return;

   char dcf77_level = DCF77_DATA_PIN & _BV (PB0);
   lcd_set_dot (5, dcf77_level);

   switch (state)
   {
   case PHASE_ACQ:
      // we use the inverted signal
      if (! dcf77_level)
      {
         uint8_t j, k;
         for (j = 0, k = clock.jiffies; j < 5; ++j)
         {
            ++ phase_acc [k];
            if (++k == F_TICK)
               k = 0;
         }
      }
      break;

   case FRAME_ACQ:
      if (0 <= clock.jiffies && clock.jiffies < N_BIT_SAMPLES)
      {
         // we use the inverted signal
         bit_samples [(uint8_t)clock.jiffies] = ! dcf77_level;
      }
      else if (clock.jiffies == N_BIT_SAMPLES)
      {
         uint8_t k, sum = 0;
         for (k = 0; k < N_BIT_SAMPLES; ++k)
            sum += bit_samples [k];

         if (++ recv_bit_cnt == 60)
            recv_bit_cnt = 0;

         if (sum > 7)
            recv_bits [recv_bit_cnt] = 1;
         else if (sum > 2)
            recv_bits [recv_bit_cnt] = 0;
         else
         {
            recv_bits [recv_bit_cnt] = RECV_BIT_MINUTE_MARK;

            if (recv_bit_cnt != 59)
            {
               // rotate bits so this is bit 59
               char tmp [60];
               for (k = 0; k < 60; ++k)
                  tmp [k] = recv_bits [(k + recv_bit_cnt + 1) % 60];
               for (k = 0; k < 60; ++k)
                  recv_bits [k] = tmp [k];
            }

            for (k = 0; k < 60; ++k)
            {
               if (k % 10 == 0)
                  putchar (' ');

               switch (recv_bits [k])
               {
               case 0: putchar ('0'); break;
               case 1: putchar ('1'); break;
               case RECV_BIT_MINUTE_MARK: putchar ('_'); break;
               default: putchar ('*'); break;
               }
            }
            put_str ("\r\n");

            if (state_seconds > 42)
            {
               // attempt to decode the time -- if it's valid, we're done!
               for (k = 17; k < 59; ++k)
               {
                  if (recv_bits [k] < 0)
                  {
                     put_str ("illegal bit\r\n");
                     return;
                  }
               }

               char dst = 0;
               if (recv_bits [17] == 0 && recv_bits [18] == 1)
                  dst = 0;
               else if (recv_bits [17] == 1 && recv_bits [18] == 0)
                  dst = 1;
               else
               {
                  put_str ("berr dst\r\n");
                  return;
               }

               if (recv_bits [20] != 1)
               {
                  put_str ("berr min_start\r\n");
                  return;
               }

               char parity = 0;
               char minutes = 0;
               bcd_decode (recv_bits + 21, 7, &parity, &minutes);
               if ((parity + recv_bits [28]) & 1)
               {
                  put_str ("perr minutes\r\n");
                  return;
               }

               parity = 0;
               char hours = 0;
               bcd_decode (recv_bits + 29, 6, &parity, &hours);
               if ((parity + recv_bits [35]) & 1)
               {
                  put_str ("perr hours\r\n");
                  return;
               }

               if (hours > 23 || minutes > 59)
               {
                  put_str ("illegal h/m\r\n");
                  return;
               }

               parity = 0;
               char day = 0;
               char dow = 0;
               char month = 0;
               char year = 0;
               bcd_decode (recv_bits + 36, 6, &parity, &day);
               bcd_decode (recv_bits + 42, 3, &parity, &dow);
               bcd_decode (recv_bits + 45, 5, &parity, &month);
               bcd_decode (recv_bits + 50, 8, &parity, &year);
               if ((parity + recv_bits [58]) & 1)
               {
                  put_str ("perr date\r\n");
                  return;
               }

               dcf77_clock.dst = dst;
               dcf77_clock.year = year;
               dcf77_clock.month = month;
               dcf77_clock.day = day;
               dcf77_clock.dow = dow;
               dcf77_clock.hours = hours;
               dcf77_clock.minutes = minutes;
               dcf77_clock.seconds = 0;

               state = SYNCED;
               state_seconds = 0;
               put_str (" -> SYNCED\r\n");
            }
         }
      }
      break;

   default:
      break;
   }
}
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

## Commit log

2021-09-21 PWM and LCD control PoC
2021-09-22 LCD driver
2021-09-23 LED driver interface via PWM
2021-09-23 Add datasheet for 5mm RGB common-cathode LED
2021-09-25 PWM module: support piezo on/off, etc.
2021-09-27 Clock rate adjustment to fine-tune (correct) crystal frequency
    [main.c]
2021-09-30 DHT22 sensor interface; double MCU clock and USART baudrate
2021-10-08 Adjust hardware plan to built prototype; LCD display driver
2021-10-23 Avoid bleeding current through internal pull-ups
    This lowers the current consumption, when DCF77 and DHT22 modules are
    off, from ~170 uA to ~67 uA.
    [dcf77.c, dht22.c]
2021-10-25 Signed-math corrections to DCF77 clock synchronizer
    [dcf77.c]
2021-10-30 Refactor LCD display driver for better performance
    - remove the intermediary storage of 3 16-bit integers
    - remove the commit phase
    - on-the-fly invert LCD_DATA bits for the negative frame
    (this makes timing asymmetrical, but only very slightly)
    [dcf77.c, main.c]
2021-11-04 Add button events and some display screens; improve sync schedule
2021-11-24 Temperature & humidity sensor scheduler and display screen
2021-12-29 More robust sensor readout
    - the sensor is read out twice after power-on, because on the first
    readout, it might still return an old value from a previous
    measurement made a long time ago, and this way the value would
    never change if the sensor was powered on for a single readout
    every now and then.
    if readouts are performed with a period that fits into the
    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
2022-01-26 Backlight control
    We only have a monochrome (white) backlight module behind the LCD.
    The RED pwm-channel is used to drive the single backlight LED.
2022-03-23 Refined button event lifecycle, allow cycling screens by holding MODE
2022-06-10 Add KiCAD files for hardware design
    This is more for documentation than design purposes,
    as the device is already functional (as a handmade prototype).
    [dcf77.kicad_pcb, dcf77.sch]
2022-06-18 Add PCB footprint for LCD backlight
    [dcf77.kicad_pcb, dcf77.sch]
2022-11-04 Updates before publication
    [dcf77.sch]
